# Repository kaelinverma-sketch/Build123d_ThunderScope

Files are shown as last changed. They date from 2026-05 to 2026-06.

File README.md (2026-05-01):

#  ThunderScope project

Assembly

This repository contains the parametric source code for the ThunderScope mechanical enclosure. The project utilizes a code-driven CAD approach to define, transform, and assemble high-precision mechanical components using the `build123d` framework.

## Methodology

### 1. Parametric Foundation
The assembly is built upon a **Master Dimension Block**. Every feature—from the 120mm vertical height of the case to the specific 0.38mm radius of the side grooves—is defined as a variable. This allows for rapid iteration and ensures that downstream transformations (like mirroring or offsetting) maintain perfect tolerances across the entire model.

### 2. Functional Component Logic
Parts are generated through functional creation functions (`create_case_body_mbs`, `create_l_bezel`, etc.). Each component follows a "Clean Room" construction logic:
* **Case Body:** Utilizes boolean subtraction and internal rail logic to define structural support and heat dissipation ribs.
* **Front Panel:** Features dual-radius fillets and cylindrical cutouts for interface components.
* **L-Bezel & End Plate:** Constructed at the origin (Y=0) to serve as master templates before being moved into final assembly positions.

### 3. The "Algebraic Flip" Assembly Pattern
To avoid the common pitfalls of the standard `mirror()` operation—which can invert the "handedness" of parts and break vertex-indexing or hole orientation—this assembly uses a **Rotation-Translation Pattern**:
* **Rotation Logic:** Flipped components (like the bottom bezel) are created using a `Rotation(180, 0, 0)` transformation. This preserves the geometric orientation while rotating the part 180 degrees around the X-axis.
* **Algebraic Transformation:** The assembly utilizes the `*` operator and the `.moved(Location())` method to create transformed copies of master parts without mutating the original geometry.

### 4. Precision Exploded View
The script is configured for an **Exploded Visualization** state, providing clear visibility of internal mating surfaces:
* **Y-Axis Explosion:** Symmetrical 3mm gaps are applied at the top (Y=123) and bottom (Y=-3) planes.
* **Z-Axis Explosion:** The rear assembly features a precision 3.10mm longitudinal shift (Z = 104.60).
* **Component Nesting:** The End Plate is seated deeper into the bezel (Z = 103.10) to simulate actual seated depth while remaining exploded from the main case.

### 5. Multi-Mode Exporting
The workflow includes a robust STEP export pipeline featuring:
* **GUI-First Interaction:** Utilizing `tkinter` for a native system "Save As" dialog.
* **CLI Fallback:** A console-based path input system ensures the script remains functional in environments where graphical libraries are not configured (common in some Homebrew or virtual environment setups).
* **Compound Aggregation:** Individual bodies are wrapped into a single `Compound` object during export to preserve the assembly structure when imported into other CAD platforms (Fusion 360, SolidWorks, etc.).

## Dependencies
* **Python 3.11+**
* **build123d:** Core CAD engine.
* **ocp_vscode:** For real-time visualization.
* **python-tk:** (Optional) Required for the graphical save dialog.

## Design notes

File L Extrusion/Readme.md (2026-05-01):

🛠 Methodology Overview
In mechanical design, a bezel secures the crystal and defines the aesthetic boundary of a watch. In software architecture, the Bezel Layer acts as the "Output Wrapper." It ensures that raw data from the logic engine is translated into a user-ready format without altering the core state.

The 3-Step Pipeline:
Response Capture: Receiving the raw data or "OpCode Result" from the Case Body.

Contextual Formatting: Transforming the data into the required output type (e.g., JSON for APIs, Markdown for Documentation, or ANSI for CLI).

Boundary Protection: Ensuring that internal system errors or raw stack traces never leak to the end-user by "clamping" them into user-friendly messages.

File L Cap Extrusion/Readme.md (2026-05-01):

Case Front: Interface & Input Resolution
This repository implements the Case Front Methodology, a design pattern focused on the entry point of a dispatch system. While the "Case Body" handles execution logic, the Case Front ensures that data is sanitized, validated, and correctly routed.

🛠 The Methodology
The Case Front serves as the translation layer between raw, unpredictable user input and the rigid, high-performance Jump Table. It operates on a Filter-then-Forward pipeline.

1. Input Normalization (The "Front" Filter)
Raw input (from APIs, CLI, or Chat) is rarely in the format the logic engine needs. The Front normalizes data (e.g., lowercase strings, type casting, or stripping whitespace) to prevent "Case Misses."

2. Schema Validation
Before reaching the dispatch body, the Front validates the structure. It checks if required keys exist or if the input falls within a valid range, preventing the "Body" from having to handle malformed data.

3. OpCode Resolution
The Front translates high-level intents into the specific keys (OpCodes) used by the Jump Table. This decouples the user-facing interface from the internal execution logic.

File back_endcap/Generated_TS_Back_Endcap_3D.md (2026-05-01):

# Generated_TS_Back_Endcap_3D Design Approach

This document outlines the methodology and geometric constraints used to generate the 3D model for the ThunderScope Back Endcap using the `build123d` python library.

## 1. Shared Base Geometry
The Back Endcap shares the standard enclosure profile used across the project:
- **Dimensions:** 103.0 mm (Width) x 30.5 mm (Height).
- **Fillets:** 4.0 mm radius on all four corners.
- **Mounting:** Four 2.1 mm radius holes located 4.0 mm from the adjacent edges (centers at (-4,-4), (-99,-4), (-4,-26.5), and (-99,-26.5)).
- **Thickness:** Extruded to a depth of 1.51 mm.

## 2. Back Endcap Specific Features

### A. Ventilation System (Fan Vents)
- **Design:** Spoke-supported arc slots surrounding a solid central hub.
- **Placement:** Centered at (-85.7, -17.2).
- **Slots:** Four SlotArcs distributed at 45°, 135°, 225°, and 315° angles with a radius of 8.2 mm and a height of 2.0 mm.

### B. Notched Interface Holes
- **Quantity:** 2 holes.
- **Radius:** 5.1 mm.
- **X-Positions:** Located at -33.5 mm and -69.6 mm.
- **Y-Position:** -20.0 mm.
- **Keyway Notches:** Two $3.0 \times 1.5$ mm rectangular notches per hole, placed diametrically opposite (top and bottom).

### C. Data & Power Cutouts
- **Large Rectangular Cutout:** $20.5 \times 2.0$ mm centered at (-51.5, -17.3).
- **Small Rectangular Cutout:** $10.5 \times 3.5$ mm centered at (-51.5, -5.6).

### D. Side Alignment & Secondary Holes
- **Alignment Holes:** Three 1.3 mm radius holes located at (-77.6, -9.1), (-77.6, -25.3), and (-93.8, -9.1).
- **Side Port:** One 2.3 mm radius circular cutout at (-15.2, -20.6).

## 3. Technical Implementation
- **Library:** `build123d`.
- **Coordinate System:** Derived from the original DXF origin point to ensure 1:1 hardware fitment.
- **Export Format:** STEP file named `Generated_TS_Back_Endcap_3D.step`.

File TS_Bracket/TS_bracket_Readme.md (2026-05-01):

# ThunderScope PCIe Bracket CAD Design Approach

This document outlines the procedural workflow and logic used to generate the ThunderScope PCIe bracket using `build123d`.

## 1. Geometric Strategy
The design follows a **Parametric Sketching** approach. Instead of using a traditional GUI, the part was constructed via code to ensure exact mathematical alignment of the PCIe standard mounting holes and the custom ThunderScope interface notches.

## 2. Structural Modules
The model is built as a `Compound` of three logical components to ensure high stability and zero geometric distortion:

### A. The Main Plate
- **Origin logic:** Sketched on the XY plane.
- **Key Modifications:** - The side tab (right-hand flange) was extended to a length of **7.25mm**. 
  - The extension was calculated by shifting the X-coordinates from the shoulder point (112.8mm) to **120.05mm**.
  - All mounting holes (radius 5.1mm and 0.8mm) were maintained at their original industrial positions.
  - The slot on the right tab was explicitly removed per the final design requirement.

### B. The Left Side Piece
- **Plane Orientation:** Sketched on a vertical plane using `Plane(origin=(0, 0, 0), x_dir=(0, 1, 0), z_dir=(1, 0, 0))`.
- **Complexity:** Contains custom rounded notches and arcs (radii 1.9mm and 2.2mm) to match the PCIe slot interface.

### C. The Notched Pin Assembly
- **Geometry:** A precision sub-assembly featuring a cylinder of radius 3.886/2mm and a hollow core for alignment.
- **Placement:** Positioned relative to the primary notch at $(10.6-7.3, 19.148-13.048)$.

## 3. Handling the 90-Degree Bend
After testing multiple iterations (3D Fillets and 2D Sketch Fillets), a **Sharp 90° Join** was selected. 
- **Reasoning:** A 1.778mm radius fillet was found to collide with the adjacent $X=11.9$ geometry and existing mounting holes, causing `BRep_API` failures.
- **Reference Match:** The final output matches the sharp-cornered grey reference model provided in the design brief.

## 4. Volumetric Analysis
The script includes a validation module to compare the material volume of the generated model against the original manufacturer's STEP file:
- **Command:** `sum(s.volume for s in final_body.solids())`
- **Goal:** To ensure the volumetric difference reflects only the intended additions (like the tab extension) and not unintended geometric artifacts.

## 5. Viewer and Export
- **Rendering:** Integrated with `ocp_vscode` for real-time visual feedback.
- **Export:** The final body is exported as a STEP file using `export_step(final_body, "TS_Bracket_NoSlot.step")`.

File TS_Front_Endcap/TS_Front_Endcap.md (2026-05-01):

# Generated_TS_Front_Endcap_3D Design Approach

This document outlines the methodology and geometric constraints used to generate the 3D models for the ThunderScope Back and Front Endcaps using the `build123d` python library.

## 1. Shared Base Geometry
Both the Front and Back Endcaps share a common outer perimeter to ensure enclosure compatibility:
- **Dimensions:** 103.0 mm (Width) x 30.5 mm (Height).
- **Fillets:** 4.0 mm radius on all four corners.
- **Mounting:** Four 2.1 mm radius holes located 4.0 mm from the adjacent edges.
- **Thickness:** Extruded to a depth of 1.51 mm.

## 2. Back Endcap Features
The Back Endcap includes specific cutouts for ventilation and internal port access:
- **Fan Vents:** Arc-slotted circular pattern with a solid center hub.
- **Data/Power Ports:** Two rectangular cutouts (10.5x3.5 and 20.5x2.0).
- **Keyed Connector Holes:** Two 5.1 mm radius holes with diametrically opposite notches.
- **Alignment:** Three 1.3 mm radius alignment holes on the left side.

## 3. Front Endcap Features (Generated_TS_Front_Endcap_3D)
The Front Endcap was modified from the base plate with the following specific requirements:

### A. Main Connector Holes (Collinear)
- **Quantity:** 4 holes.
- **Vertical Position:** Centered at 20.045 mm from the bottom edge ($Y = -10.455$ relative to top edge).
- **Type:** Keyed holes ($R=5.1$ mm) with $3.0 \times 1.5$ mm rectangular notches at the top and bottom (diametrically opposite).

### B. Top Horizontal Slots
- **Dimensions:** 5.0 mm (Length) x 2.5 mm (Height).
- **Quantity:** 3 slots.
- **Placement:** Positioned at the midpoints between the adjacent main connector holes.
- **Top Offset:** Top edge of the slot is exactly 2.74 mm from the top edge of the plate.

### C. Bottom Horizontal Slots
- **Dimensions:** 12.0 mm (Length) x 3.0 mm (Height).
- **Quantity:** 2 slots.
- **X-Positioning:** Left edges located exactly at 36.675 mm and 57.325 mm from the plate's left edge.
- **Bottom Offset:** Bottom edge of the slot is exactly 2.74 mm from the bottom edge of the plate.

### D. Side Alignment Holes
- **Quantity:** 3 holes.
- **Radius:** 1.3 mm.
- **Coordinates:** Reused from the Back Endcap layout for internal chassis consistency.

## 4. Technical Implementation
- **Library:** `build123d` (OpenCASCADE-based).
- **Version Compatibility:** Used positional arguments for `GridLocations` to ensure stability across library updates.
- **Export Format:** STEP (Standard for the Exchange of Product model data) for manufacturing and CAD integration.

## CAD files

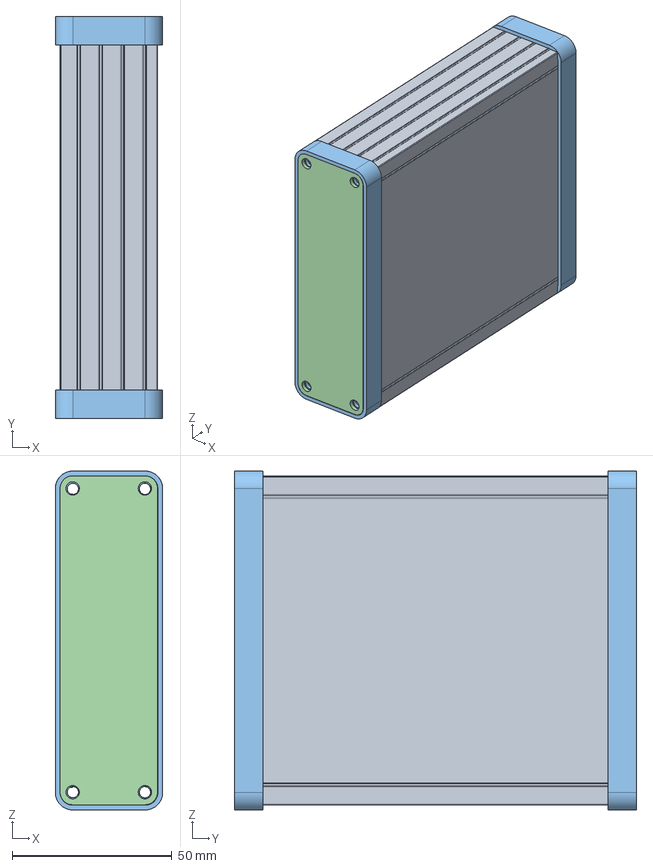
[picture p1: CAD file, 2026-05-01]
ASSEMBLY/ThunderScope Assembly.step
33.6 x 126.0 x 106.2 mm

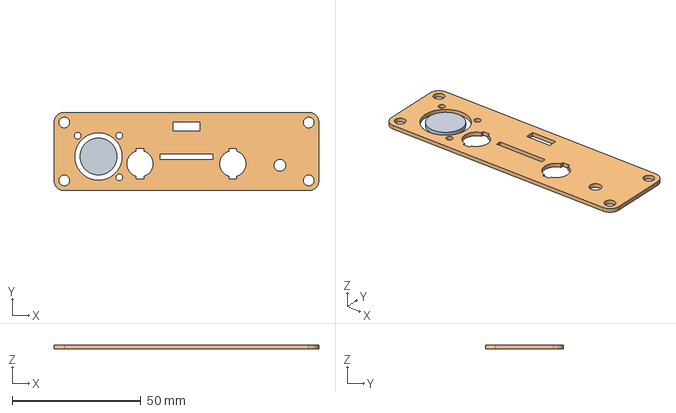
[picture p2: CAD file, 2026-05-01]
back_endcap/Generated_TS_Back_Endcap_3D.step
103.0 x 30.5 x 1.51 mm

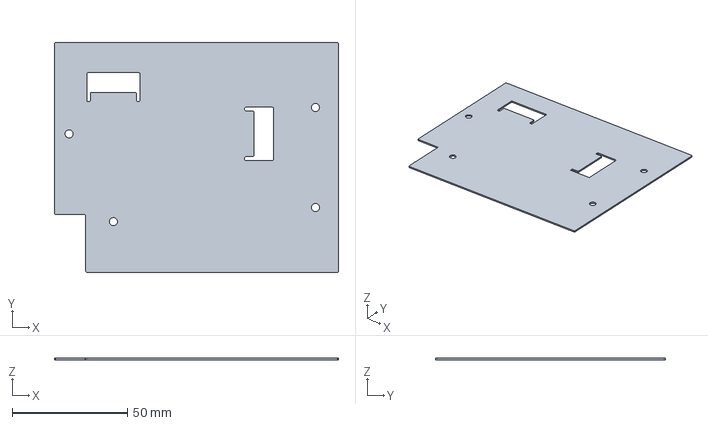
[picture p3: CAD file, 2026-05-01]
Interposer/Interposer_Board_JoneyTech.step.step
123.0 x 99.5 x 0.74 mm

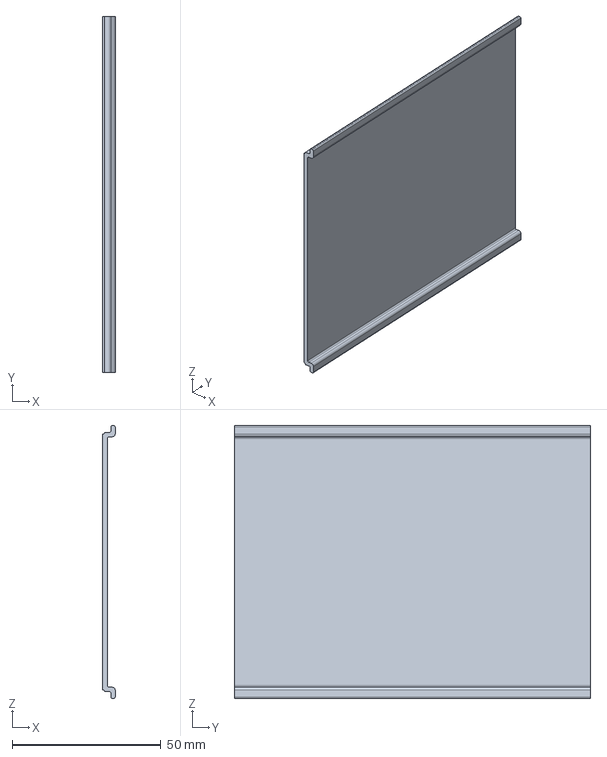
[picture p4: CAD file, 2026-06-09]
L Cap Extrusion/L_Cap_Extrusion.step
4.22 x 120.0 x 91.9 mm

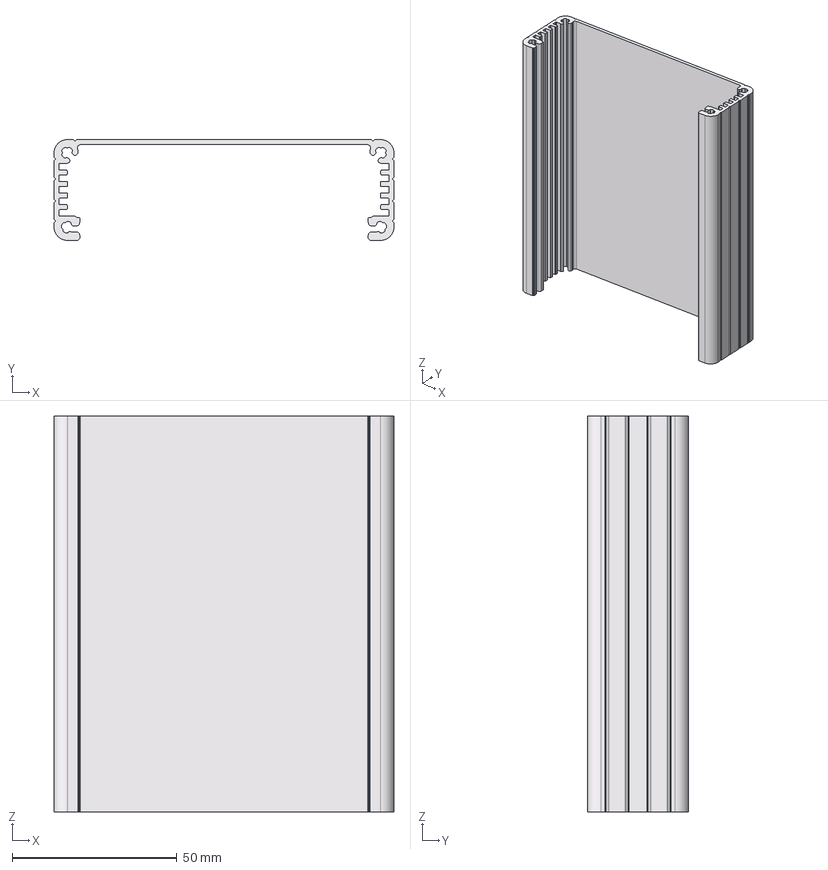
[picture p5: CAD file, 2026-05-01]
L Extrusion/L Extrusion.step
103.0 x 30.5 x 120.0 mm

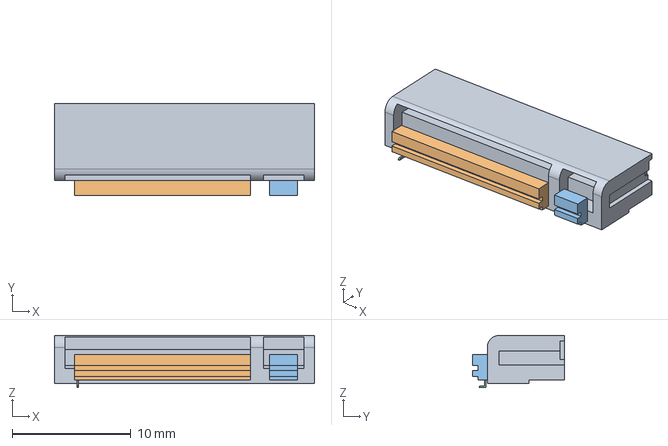
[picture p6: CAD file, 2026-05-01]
TB_board/fpc_model.step
21.9 x 7.75 x 4.40 mm

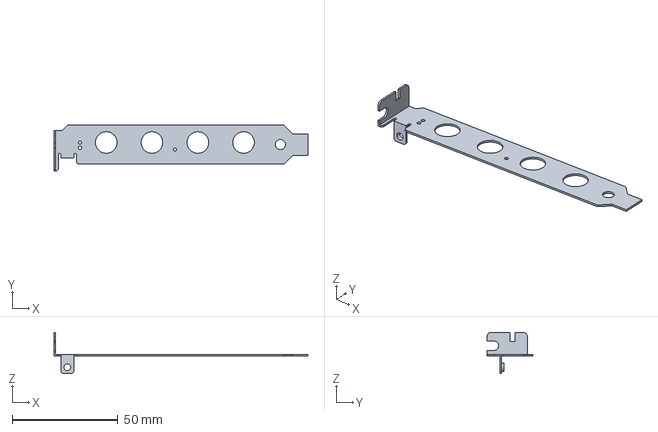
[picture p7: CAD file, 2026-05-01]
TS_Bracket/TS_Bracket_NoSlot.step
120.0 x 21.6 x 19.5 mm

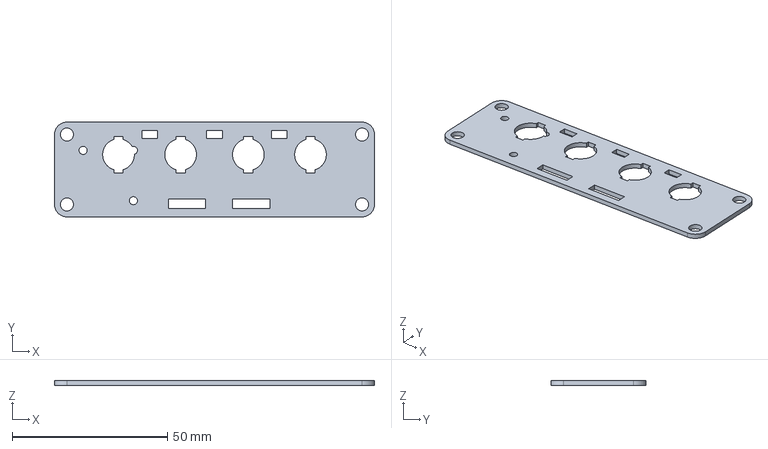
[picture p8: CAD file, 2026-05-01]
TS_Front_Endcap/TS_Front_Endcap.step
103.0 x 30.5 x 1.51 mm

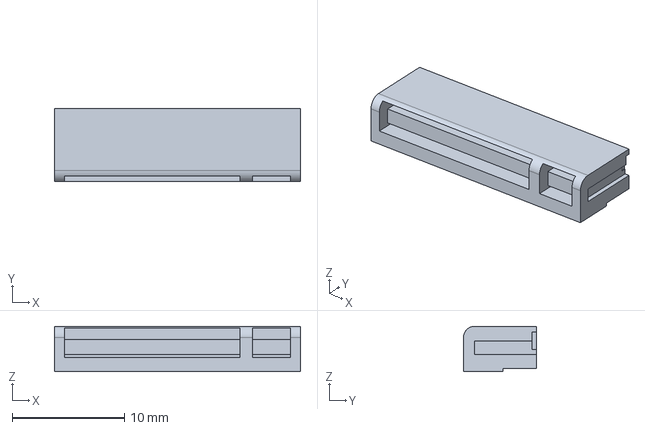
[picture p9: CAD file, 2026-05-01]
TB_board/fpc_final.step
21.9 x 6.50 x 4.05 mm

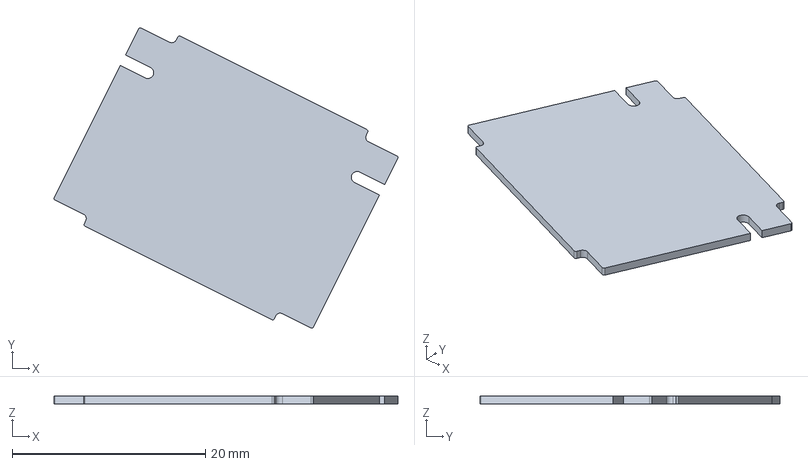
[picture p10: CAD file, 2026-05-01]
TB_board/adaptor_board.step
35.6 x 31.1 x 0.781 mm

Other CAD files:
ASSEMBLY/Source_Thunderscope-Assembly.step
L Cap Extrusion/L_Cap_Extrusion.stl

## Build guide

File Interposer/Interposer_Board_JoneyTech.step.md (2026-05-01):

# Interposer Plate - README

A thin custom interposer plate (0.74 mm thick) with complex outer shape, two window cutouts, and four mounting holes.  
Designed using **build123d** in Python.

## Model Specifications
- Thickness: **0.74 mm**
- Fillet on all vertical edges: **0.50 mm**
- Units: Millimeters (mm)
- Four circular holes of diameter **3.5 mm**

## Design Approach (Step-by-Step)

The model is built following a clean and efficient CAD workflow:

1. **Define Geometry Data**  
   All coordinates and hole positions are stored at the top for easy modification and clarity.

2. **Create 2D Sketch**  
   - Draw the outer profile using `Polyline`.
   - Convert it into a face using `make_face()`.
   - Subtract the two irregular windows using `Mode.SUBTRACT`.
   - Subtract the four circular holes using `Circle` with `Mode.SUBTRACT`.

3. **Extrude the Sketch**  
   Extrude the final 2D sketch by **0.74 mm** to create the 3D thin plate.

4. **Apply Fillets**  
   Select all vertical edges (parallel to Z-axis) and apply **0.50 mm** fillet for smooth corners.

5. **Export & Output**  
   - Export the model as `Interposer.step`
   - Print the final volume for reference
   - Display the model in the viewer (if `ocp-vscode` is installed)

This approach keeps all boolean operations in 2D (which is faster and more stable) before going to 3D.

## How to Generate the Model

### Requirements
```bash
pip install build123d ocp-vscode

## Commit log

2026-05-01 Add README for ThunderScope project overview
    This README provides an overview of the ThunderScope project, detailing its methodology, assembly pattern, exporting capabilities, and dependencies.
2026-06-08 Rename Generated_TS_Front_Endcap_3D (2).step to TS_Front_Endcap.step
    [TS_Front_Endcap.step]
2026-06-08 Add Interposer_Board_JoneyTech.step.step file
    [Interposer_Board_JoneyTech.step.step]
2026-06-09 Update and rename CASE Front.py to L_Cap_Extrusion.py
